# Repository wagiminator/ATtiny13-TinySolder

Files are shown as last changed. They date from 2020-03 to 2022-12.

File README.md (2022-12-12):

# TinySolder - T12 Soldering Station based on ATtiny13A
TinySolder is a simple T12 Quick Heating Soldering Station based on the ATtiny13A featuring in less than 500 bytes of code:
- Temperature measurement of the tip
- Direct control of the heater
- Temperature control via potentiometer
- Handle movement detection (by checking tilt switch)
- Time driven sleep/power off mode if iron is unused (movement detection)

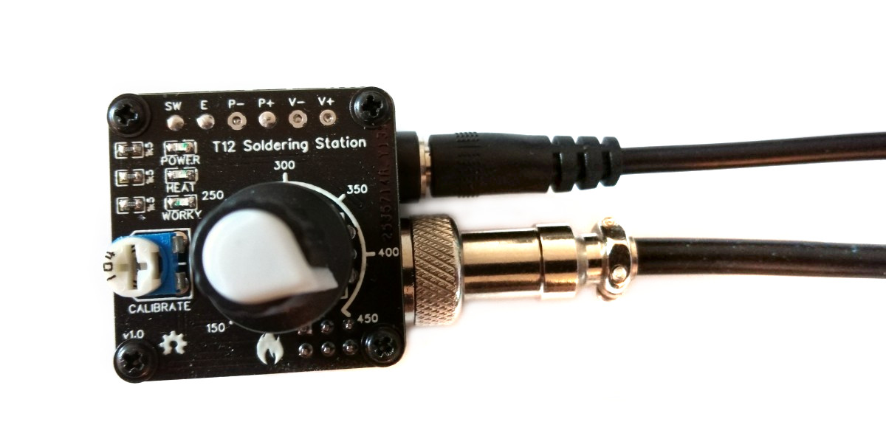
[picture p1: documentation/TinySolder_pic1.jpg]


- Project Video (YouTube): https://youtu.be/LOpmxG2Fvpo
- Design Files (EasyEDA): https://easyeda.com/wagiminator/y-attiny13-soldering-station-smd

# Hardware
## Heater Control
To switch the heater on and off, it is controlled via an [AO4435](https://datasheet.lcsc.com/szlcsc/Alpha-Omega-Semicon-AOS-AO4435_C79714.pdf) p-channel MOSFET. The MOSFET is designed for voltages up to 30V and currents up to 10A. Its resistance is relatively low at 14 milliohms, which guarantees high efficiency and low heat generation on the MOSFET itself. There are many 4435 MOSFETs available from different manufacturers with slightly different specifications. It should be ensured that a 4435 with a gate-source voltage of +/-25V is selected.

## Temperature Measurement
A thermocouple (temperature sensor) is located inside the T12 soldering tip. It creates a very small voltage depending on the temperature difference between the hot end and the cold junction. To measure this, the heater must be switched off since heater and thermocouple are connected in series. The low voltage is amplified by the OpAmp and measured by the ADC of the microcontroller. The gain factor of the OpAmp is controlled via the calibration potentiometer within fixed limits. The [LMV358](https://datasheet.lcsc.com/szlcsc/Texas-Instruments-TI-LMV358IDR_C63813.pdf) is a very cheap and versatile OpAmp, but not the ideal choice for this task because it has a fairly high input offset voltage and is quite noisy. For this kind of soldering station, however, it delivers completely sufficient values. Should a higher accuracy be required, an [OPA2330AIDR](https://datasheet.lcsc.com/szlcsc/1810181613_Texas-Instruments-OPA2330AIDR_C128746.pdf) or [OPA2333AIDR](https://datasheet.lcsc.com/szlcsc/1809200040_Texas-Instruments-OPA2333AIDR_C38732.pdf) can be used instead of the LMV358. Since these OpAmps have the same pinout, no further changes need to be made.

## Voltage Regulator
Since the ATtiny13A and the OpAmp only consume very little power, a small voltage regulator of the type [78L05](https://datasheet.lcsc.com/szlcsc/1811151533_Guangdong-Hottech-78L05_C181132.pdf) is completely sufficient for obtaining the 5V supply voltage. Because of the low current it has to deliver, it hardly heats up despite the relatively high voltage gradient.

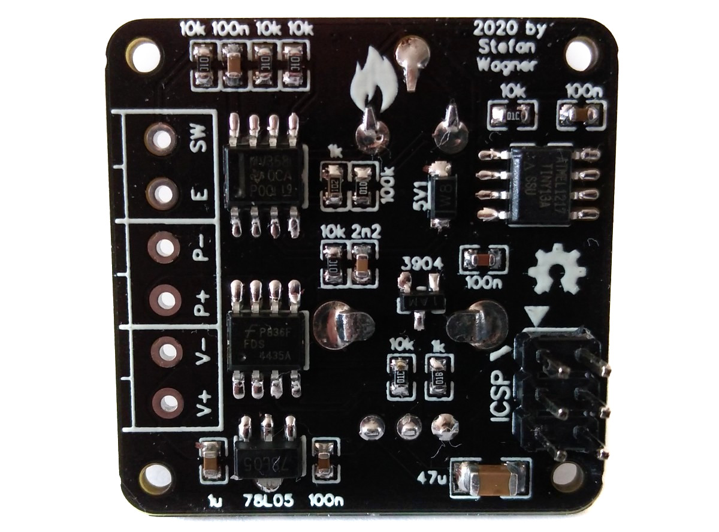
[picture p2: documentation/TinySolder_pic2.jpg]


# Software
## Implementation
In order to determine the temperature of the soldering tip, the heater must first be switched off. The output voltage of the OpAmp is then measured using the analog-to-digital converter (ADC) and the temperature is determined from this using a two-step linear approximation. The setting of the temperature selection potentiometer is also determined via the ADC. If the temperature of the soldering tip is below the selected setpoint, the heater is then switched on again via the MOSFET, otherwise it remains off for the time being.

A sleep timer runs all the time, which is reset by a pin change interrupt as soon as the tilt switch in the handle of the soldering iron changes its state. If the handle is not moved for about 5 minutes, the system switches to sleep mode, in which the temperature is reduced to about 125°C. If the handle is not moved for another 5 minutes, the heater will be switched off completely. As soon as the handle is moved, the operating mode is switched back to.

The main loop of the code is shown below:
```c
// Loop
while(1) {
  // Read potentiometer setting and calculate setpoint accordingly
  poti = ADC_read(pinADC(POTI));
  if (poti < 512) setpoint = (uint32_t)(( poti        * (TEMP300 - TEMP150))>>9) + TEMP150;
  else            setpoint = (uint32_t)(((poti - 512) * (TEMP450 - TEMP300))>>9) + TEMP300;

  // Set heater according to temperature reading and setpoint
  pinLow(HEATER);                                 // shut off heater
  _delay_us(TIME2SETTLE);                         // wait for voltages to settle
  temp = ADC_read(pinADC(TEMP));                  // read temperature
  smooth = ((smooth << 3) - smooth + temp) >> 3;  // low pass filter
  if (smooth < setpoint) pinHigh(HEATER);         // turn on heater if below setpoint

  // Set status LED according to temperature and setpoint
  pinLow(LED);
  if ((smooth + 10 > setpoint) && (setpoint + 10 > smooth)) pinHigh(LED);

  // Some timing
  if (handleTimer++ > TIME2SLEEP/CYCLETIME*1000) sleep(); // sleep mode if handle unused
  _delay_ms(CYCLETIME - 8);                               // wait for next cycle
}
```

## Compiling and Uploading
### If using the Arduino IDE
- Make sure you have installed [MicroCore](https://github.com/MCUdude/MicroCore).
- Go to **Tools -> Board -> MicroCore** and select **ATtiny13**.
- Go to **Tools** and choose the following board options:
  - **Clock:**  1.2 MHz internal osc.
  - **BOD:**    BOD 2.7V
  - **Timing:** Micros disabled
- Connect your programmer to your PC and to the ICSP header on the TinySolder board.
- Go to **Tools -> Programmer** and select your ISP programmer (e.g. [USBasp](https://aliexpress.com/wholesale?SearchText=usbasp)).
- Go to **Tools -> Burn Bootloader** to burn the fuses.
- Open TinySolder.ino and click **Upload**.

### If using the precompiled hex-file
- Make sure you have installed [avrdude](https://learn.adafruit.com/usbtinyisp/avrdude).
- Connect your programmer to your PC and to the ICSP header on the TinySolder board.
- Open a terminal.
- Navigate to the folder with the hex-file.
- Execute the following command (if necessary replace "usbasp" with the programmer you use):
  ```
  avrdude -c usbasp -p t13 -U lfuse:w:0x2a:m -U hfuse:w:0xfb:m -U flash:w:tinysolder.hex
  ```

### If using the makefile (Linux/Mac)
- Make sure you have installed [avr-gcc toolchain and avrdude](http://maxembedded.com/2015/06/setting-up-avr-gcc-toolchain-on-linux-and-mac-os-x/).
- Connect your programmer to your PC and to the ICSP header on the TinySolder board.
- Open a terminal.
- Navigate to the folder with the makefile and sketch.
- Run `PROGRMR=usbasp make install` to compile, burn the fuses and upload the firmware (change PROGRMR accordingly).

# Building Instructions
In addition to the components for the PCB you will need the following:
- 3D-printed case
- GX12 Aviator Plug (4- or 5-pin depending on your iron handle)
- DC Power Jack (5.5 * 2.1 mm)
- Rocker Switch (KCD1 15 * 10 mm)
- Some wires
- 4 Self-tapping screws (2.3 * 5 mm)

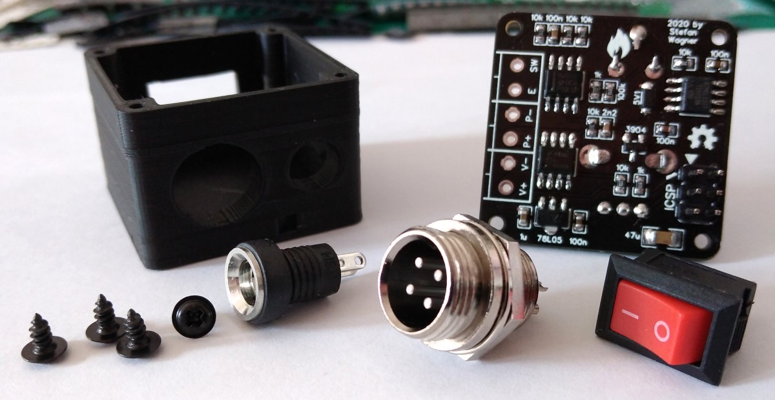
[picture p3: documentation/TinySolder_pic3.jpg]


Make sure that all parts fit nicely into the case. Solder the wires to the connectors and protect them with heat shrinks. Use thick wires (AWG18) for the power connections. Make all connections according to the schematic down below but keep in mind, that there's no standard pinout. Solder the wires directly to the corresponding pads on the pcb. To make the soldering station ESD-safe, connect the earth (E) terminal of the aviator plug to a female dupont connector and glue it into the corresponding opening on the case. Now you can connect the soldering station via a male dupont connector to an earth terminal. Upload the firmware and screw the pcb on top of the case.

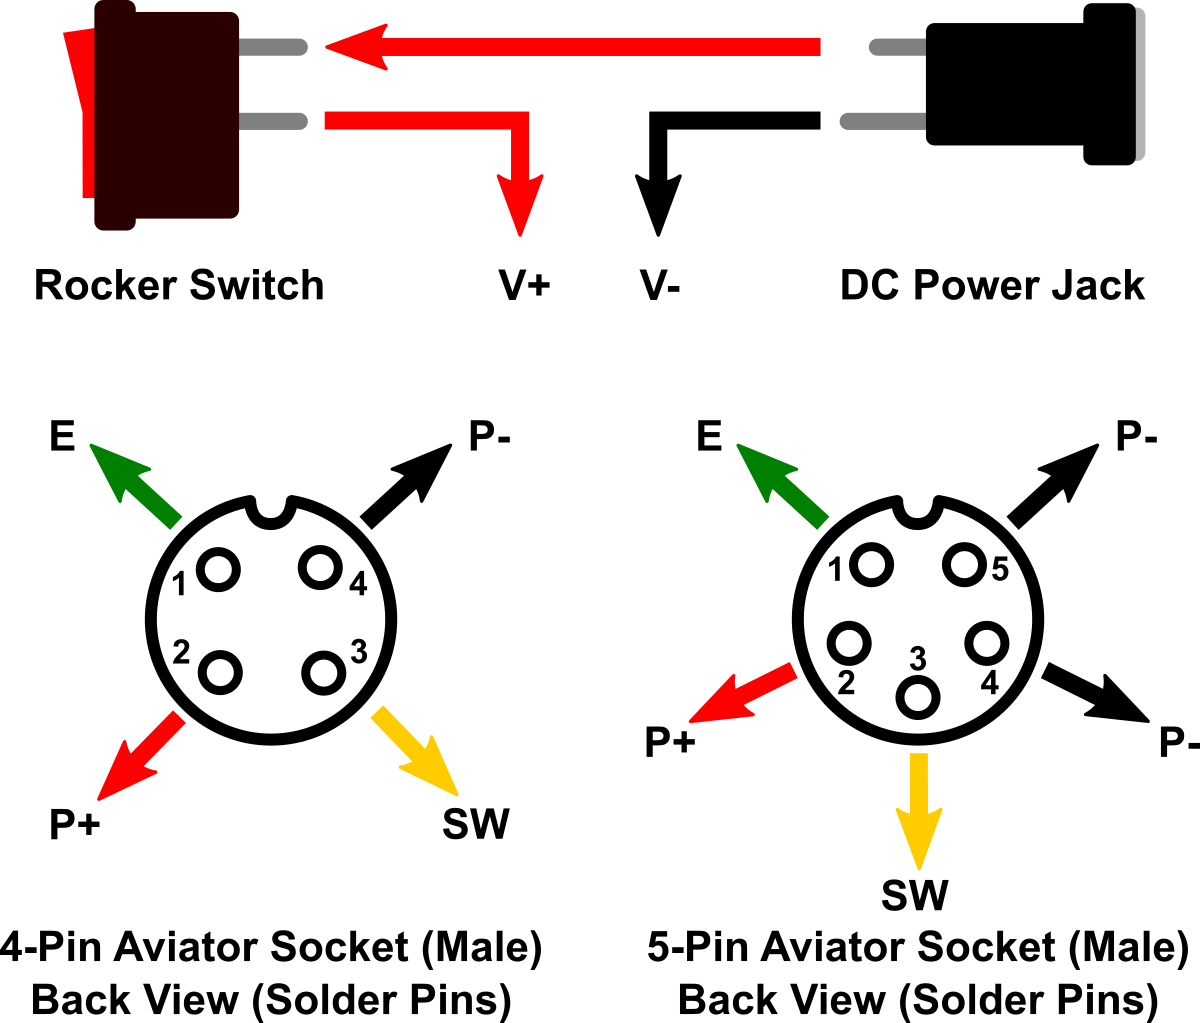
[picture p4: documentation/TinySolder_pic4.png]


The pinout shown works for the [Quecoo handles from aliexpress](https://aliexpress.com/wholesale?SearchText=quecoo+handle). Different handles may have different pinouts. If you are assembling your handle yourself, follow the scheme shown below. The video by [John Glavinos (electronics4all)](https://www.youtube.com/watch?v=DcmiFfuZw38) shows how it's done.

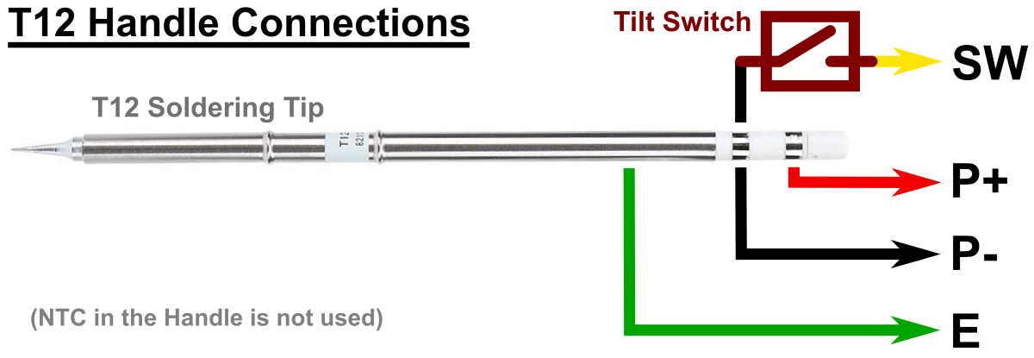
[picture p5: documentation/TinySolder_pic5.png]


# Operating Instructions
## Power Supply Specification Requirements
Choose a power supply with an output voltage between 16V and 24V which can provide an output current according to the table below. The power supply must be well stabilized. The current and power is determined by the resistance (R = 8 Ohm) of the heater.

|Voltage (U)|Current (I) = U / R|Power (P) = U² / R|
|:-|:-|:-|
|16 V|2.00 A|32 W|
|17 V|2.13 A|36 W|
|18 V|2.25 A|41 W|
|19 V|2.38 A|45 W|
|20 V|2.50 A|50 W|
|21 V|2.63 A|55 W|
|22 V|2.75 A|61 W|
|23 V|2.88 A|66 W|
|24 V|3.00 A|72 W|

## Calibrating
For calibration you need a [soldering iron tips thermometer](https://aliexpress.com/wholesale?SearchText=digital+soldering+tip+thermometer). For best results wait at least three minutes after switching on the soldering station before you start the calibration. Calibrate at your prefered temperature using the
trimpot.

## Indicator LEDs
|LED|Color|Status|
|:-|:-|:-|
|POWER|blue|lights up when the station is receiving power|
|HEAT|red|tip temperature has not reached setpoint yet|
|WORKY|green|tip temperature is at setpoint - iron is worky|
|HEAT + WORKY|red + green|blinking: iron is in sleep mode; steady: iron is in off mode; move handle to wake up|

# References, Links and Notes
1. [ATtiny13A Datasheet](http://ww1.microchip.com/downloads/en/DeviceDoc/doc8126.pdf)
2. [LMV358 Datasheet](https://datasheet.lcsc.com/szlcsc/Texas-Instruments-TI-LMV358IDR_C63813.pdf)
3. [T12 Handles on Aliexpress](https://aliexpress.com/wholesale?SearchText=T12+GX12-4pin+handle)
4. [T12 Soldering Tips on Aliexpress](https://aliexpress.com/wholesale?SearchText=T12+soldering+tips)
5. [GX12 Aviator Plugs on Aliexpress](https://aliexpress.com/wholesale?SearchText=GX12+4pin+aviator)
6. [T12 Soldering Station based on ATmega328P](https://github.com/wagiminator/ATmega-Soldering-Station)

# License


This work is licensed under Creative Commons Attribution-ShareAlike 3.0 Unported License. 
(http://creativecommons.org/licenses/by-sa/3.0/)

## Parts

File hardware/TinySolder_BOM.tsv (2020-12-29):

ID | Name | Designator | Footprint | Quantity | Manufacturer Part | Manufacturer | Supplier | Supplier Part | LCSC Assembly
1 | LMV358IDR | U3 | SOP-8_150MIL | 1 | LMV358IDR | TI | LCSC | C63813 | Yes
2 | MMBT3904 | Q2 | SOT-23_1 | 1 | 2n3904S-RTK/PS | KEC | LCSC | C18536
3 | 5V1 | D1 | ZENER-SOD-123 | 1 | BZT52C5V1 | (MDD) Jiangsu Yutai Elec | LCSC | C173407 | Yes
4 | 10k | R7,R6,R5,R1,R14,R8 | 0603 | 6 | 0603WAF1002T5E | UniOhm | LCSC | C25804
5 | 1k | R13,R11,R4,R12,R9 | 0603 | 5 | 0603WAF1001T5E | UniOhm | LCSC | C21190
6 | 100k | R3 | 0603 | 1 | 0603WAF1003T5E | UniOhm | LCSC | C25803
7 | WORKY | LED2 | LED-0603 | 1 | 19-217/GHC-YR1S2/3T | EVERLIGHT | LCSC | C72043 | Yes
8 | HEAT | LED3 | LED-0603 | 1 | KT-0603R | KENTO | LCSC | C2286 | Yes
9 | 10K | R10 | RES-TH_RK09K1130A5R | 1 | RK09K1130A5R | ALPS Electric | LCSC | C209779
10 | 78L05 | U2 | SOT-89-3_L4.5-W2.5-P1.50-LS4.2-BR | 1 | 78L05 | Guangdong Hottech | LCSC | C181132 | Yes
11 | KF350-3.5mm | P2,P1,P3 | KF350-2P | 3 | WJ2EDGVC-5.08-2P | ReliaPro | LCSC | C8445
12 | ICSP-6 | ICSP1 | ICSP-6 | 1 | ?
13 | AO4435 | Q1 | SOP-8_150MIL | 1 | AO4435 | Alpha & Omega Semicon | LCSC | C79714 | Yes
14 | POWER | LED1 | LED-0603 | 1 | 19-217/BHC-ZL1M2RY/3T | EVERLIGHT | LCSC | C72041 | Yes
15 | 100n | C5,C1,C4,C7 | 0603 | 4 | CC0603KRX7R9BB104 | YAGEO | LCSC | C14663
16 | 2n2 | C3 | 0603 | 1 | 0603B222K500NT | FH | LCSC | C1604
17 | 47u | C2 | 1206 | 1 | CL31A476MQHNNNE | SAMSUNG | LCSC | C68361
18 | 1u | C6 | 0603 | 1 | CL10A105KB8NNNC | SAMSUNG | LCSC | C15849
19 | 100k | R2 | RM065 | 1 |  |  | LCSC
20 | ATTINY13A-SSU | U1 | SOP-8_150MIL | 1 | ATTINY13A-SSU | MICROCHIP | LCSC | C14075

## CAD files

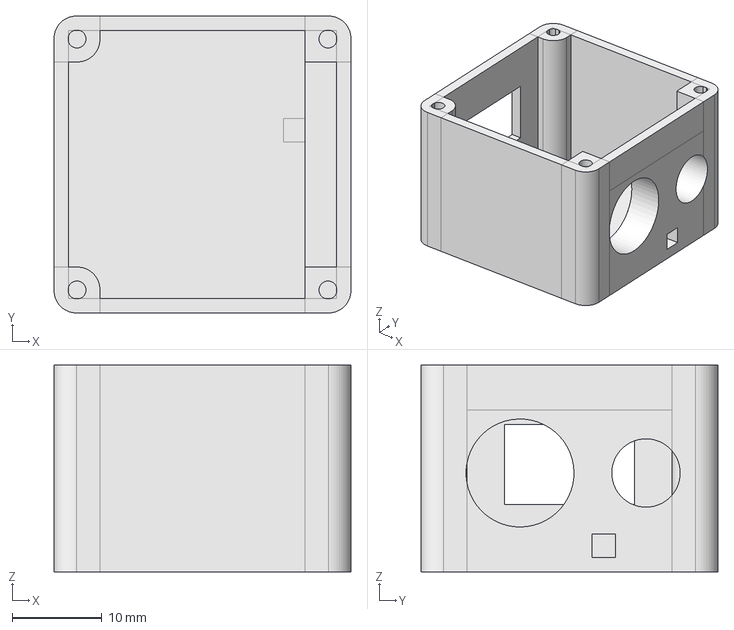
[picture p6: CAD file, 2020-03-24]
3dprint/TinySolder_case.fcstd
33.0 x 33.0 x 23.0 mm

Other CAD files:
3dprint/TinySolder_case.stl

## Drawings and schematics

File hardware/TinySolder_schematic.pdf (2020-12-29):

## Connectors

## Microcontroller

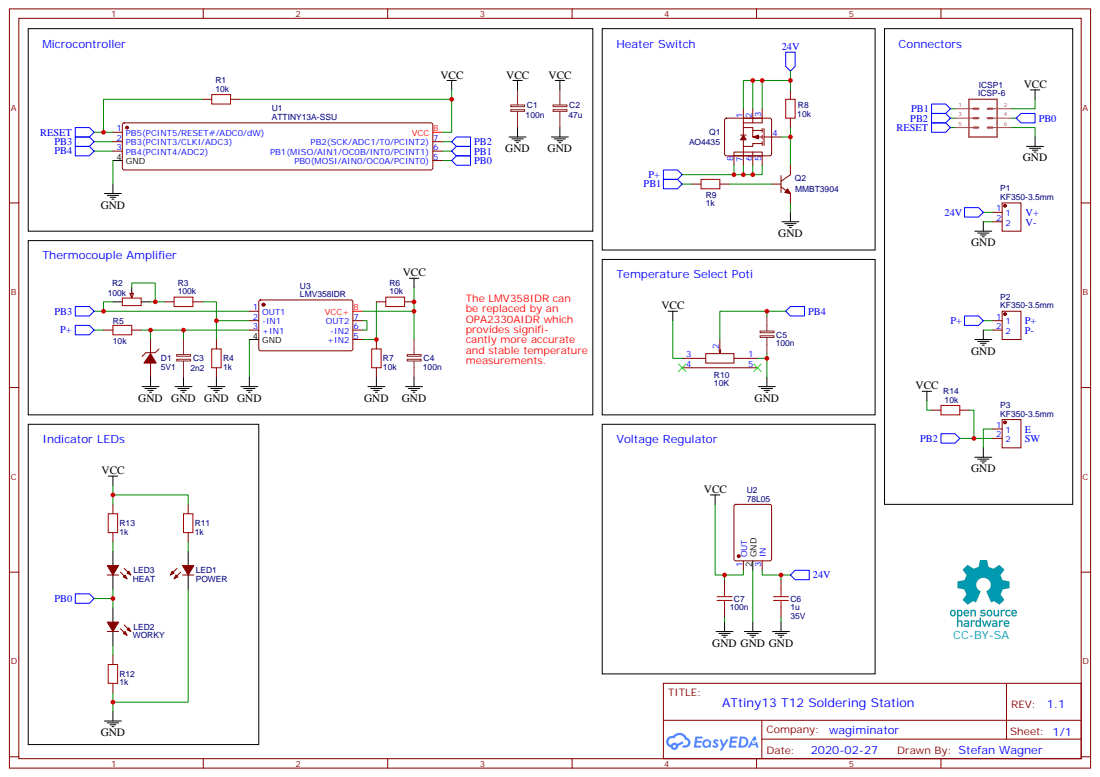
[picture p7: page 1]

The LMV358IDR can
be replaced by an
OPA2330AIDR which
provides signifi-
cantly more accurate
and stable temperature
measurements.

Drawn By: Stefan Wagner

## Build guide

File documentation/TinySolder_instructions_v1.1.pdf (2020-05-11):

## How to build the Tiny T12 SolderingStation

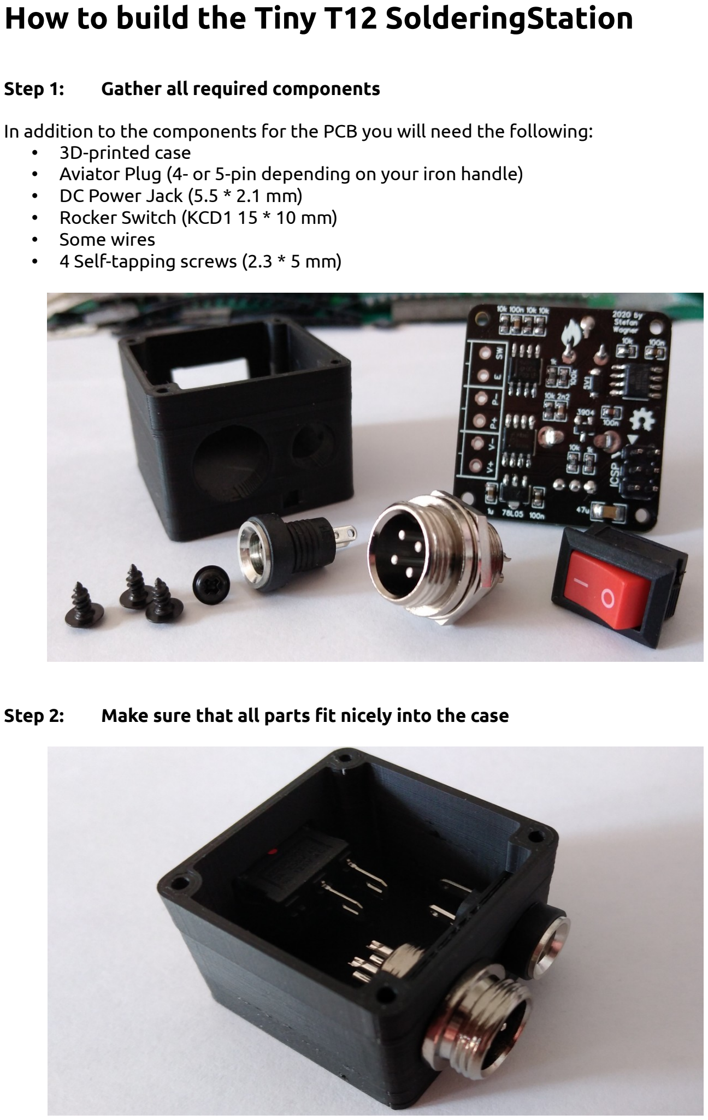
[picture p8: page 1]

Step 1: Gather all required components

In addition to the components for the PCB you will need the following:
- 3D-printed case
- Aviator Plug (4- or 5-pin depending on your iron handle)
- DC Power Jack (5.5 * 2.1 mm)
- Rocker Switch (KCD1 15 * 10 mm)
- Some wires
- 4 Self-tapping screws (2.3 * 5 mm)
Step 2: Make sure that all parts fit nicely into the case

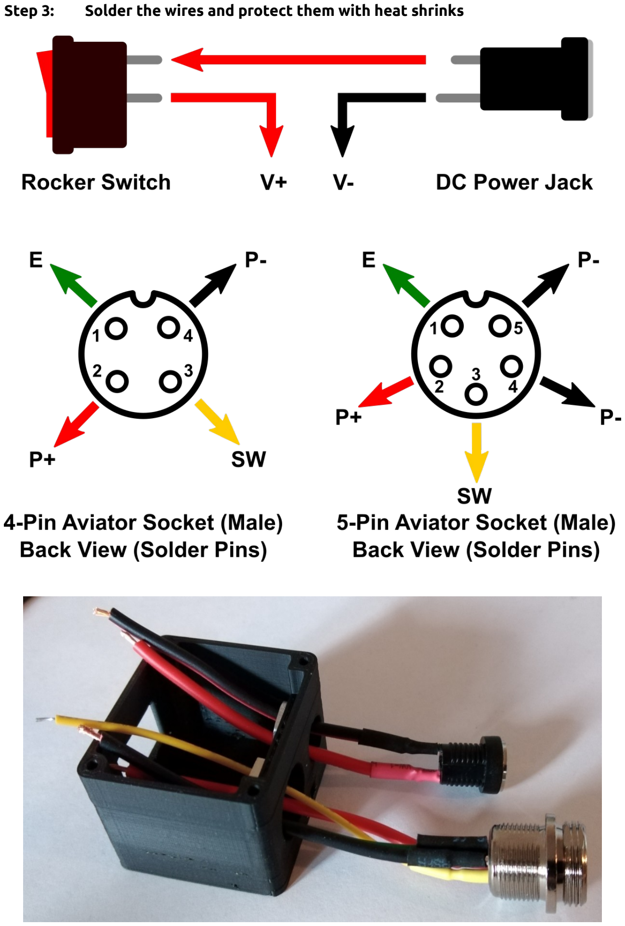
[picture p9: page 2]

Step 3: Solder the wires and protect them with heat shrinks

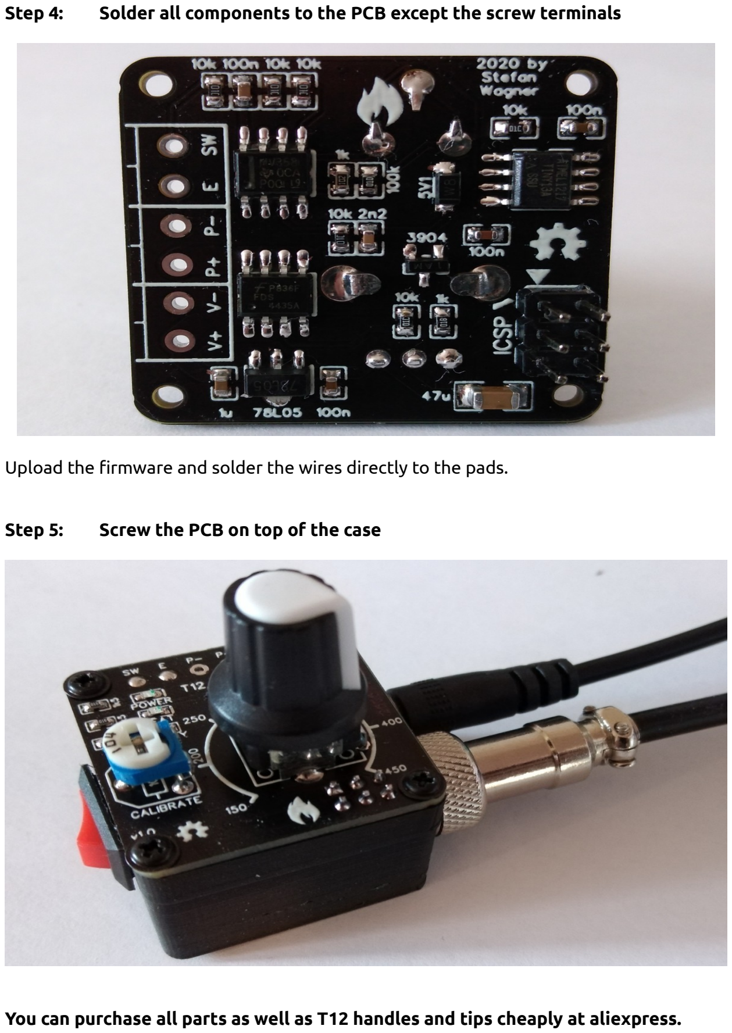
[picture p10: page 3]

Step 4: Solder all components to the PCB except the screw terminals

Upload the firmware and solder the wires directly to the pads.

Step 5: Screw the PCB on top of the case

You can purchase all parts as well as T12 handles and tips cheaply at aliexpress.

Choose a power supply with an output voltage between 16V and 24V which can provide an output current according to the table below. The power supply must be well stabilized. The current and power is determined by the resistance (R = 8 Ohm) of the heater.

Voltage (U) | Current (I) = U / R | Power (P) = U² / R
16 V | 2.00 A | 32 W
17 V | 2.13 A | 36 W
18 V | 2.25 A | 41 W
19 V | 2.38 A | 45 W
20 V | 2.50 A | 50 W
21 V | 2.63 A | 55 W
22 V | 2.75 A | 61 W
23 V | 2.88 A | 66 W
24 V | 3.00 A | 72 W

A 19V supply works best in terms of both, speed and stable temperature readings. Heat-up time to 320°C will be around 12 seconds with a 19V, 8 seconds with a 24V power supply.

TinySolder Building Instructions v1.1, 2020 by Stefan Wagner. Recent project files can be found at https://easyeda.com/wagiminator/y-attiny13-soldering-station-smd. This work is licensed under Creative Commons Attribution-ShareAlike 3.0 Unported License (http://creativecommons.org/licenses/by-sa/3.0/).

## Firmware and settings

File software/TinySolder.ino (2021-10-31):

// ===================================================================================
// Project:   TinySolder - T12 Soldering Station based on ATtiny13A
// Version:   v1.1
// Year:      2020
// Author:    Stefan Wagner
// Github:    https://github.com/wagiminator
// EasyEDA:   https://easyeda.com/wagiminator
// License:   http://creativecommons.org/licenses/by-sa/3.0/
// ===================================================================================
//
// Description:
// ------------
// Simple T12 Quick Heating Soldering Station featuring:
// - Temperature measurement of the tip
// - Direct control of the heater
// - Temperature control via potentiometer
// - Handle movement detection (by checking tilt switch)
// - Time driven sleep/power off mode if iron is unused (movement detection)
//
// Indicator LEDs:
// - steady blue          - station is powered
// - steady red           - tip temperature has not reached setpoint yet
// - steady green         - tip temperature is at setpoint - iron is worky
// - blinking red/green   - iron is in sleep mode - move handle to wake up
// - steady red and green - iron is in off mode - move handle to start again
//
// Power supply should be in the range of 16V/2A to 24V/3A and well
// stabilized.
//
// For calibration you need a soldering iron tips thermometer. For best results
// wait at least three minutes after switching on the soldering station before 
// you start the calibration. Calibrate at your prefered temperature.
//
// Wiring:
// -------
//                         +-\/-+
//      --- RST ADC0 PB5  1|°   |8  Vcc
// Temp ------- ADC3 PB3  2|    |7  PB2 ADC1 -------- Tilt Switch
// Poti ------- ADC2 PB4  3|    |6  PB1 AIN1 OC0B --- Heater
//                   GND  4|    |5  PB0 AIN0 OC0A --- LED
//                         +----+
//
// Compilation Settings:
// ---------------------
// Controller:  ATtiny13A
// Core:        MicroCore (https://github.com/MCUdude/MicroCore)
// Clockspeed:  1.2 MHz internal
// BOD:         BOD 2.7V
// Timing:      Micros disabled
//
// Leave the rest on default settings. Don't forget to "Burn bootloader"!
// No Arduino core functions or libraries are used. Use the makefile if 
// you want to compile without Arduino IDE.
//
// Fuse settings: -U lfuse:w:0x2a:m -U hfuse:w:0xfb:m


// ===================================================================================
// Libraries and Definitions
// ===================================================================================

// Libraries
#include <avr/io.h>             // for gpio
#include <avr/sleep.h>          // for the sleep modes
#include <avr/interrupt.h>      // for the interrupts
#include <util/delay.h>         // for delays

// Pin definitions
#define LED           PB0       // connected to indicator LEDs
#define HEATER        PB1       // connected to gate of heater control MOSFET
#define SWITCH        PB2       // connected to tilt switch of handle
#define TEMP          PB3       // connected to P+ of tip (temp measurement)
#define POTI          PB4       // connected to temp selection pot

// ADC temperature calibration values
#define TEMPSLEEP     100       // ADC3 in sleep mode
#define TEMP150       118       // ADC3 at 150°C
#define TEMP300       221       // ADC3 at 300°C
#define TEMP450       324       // ADC3 at 450°C

// Timer definitions
#define CYCLETIME      50       // cycle delay time in milliseconds
#define TIME2SETTLE   900       // voltage settle time in microseconds
#define TIME2SLEEP    300       // time to enter sleep mode in seconds
#define TIME2OFF      600       // time to shut off heater in seconds

// Pin manipulation macros
#define pinInput(x)   DDRB  &= ~(1<<(x))  // set pin to INPUT
#define pinOutput(x)  DDRB  |=  (1<<(x))  // set pin to OUTPUT
#define pinLow(x)     PORTB &= ~(1<<(x))  // set pin to LOW
#define pinHigh(x)    PORTB |=  (1<<(x))  // set pin to HIGH
#define pinToggle(x)  PINB  |=  (1<<(x))  // TOGGLE pin
#define pinDisable(x) DIDR0 |=  (1<<(x))  // disable digital input buffer
#define pinIntEn(x)   PCMSK |=  (1<<(x))  // enable pin change interrupt
#define pinRead(x)    (PINB &   (1<<(x))) // READ pin
#define pinADC(x)     ((x)==2?1:((x)==3?3:((x)==4?2:0))) // convert pin to ADC port

// Global variables
volatile uint16_t handleTimer;  // time since the handle was last moved

// ===================================================================================
// ADC Implementation
// ===================================================================================

// Init ADC
void ADC_init(void) {
  ADCSRA = (1<<ADEN)                  // enable ADC
         | (1<<ADPS1) | (1<<ADPS0)    // set ADC clock prescaler to 8
         | (1<<ADIE);                 // ADC interrupts enable
}

// Average several ADC readings in sleep mode to denoise
uint16_t ADC_read(uint8_t port) {
  uint16_t result = 0;
  ADCSRA |= (1<<ADIF);                // turn off any pending interrupt
  ADMUX = port;                       // set port and reference to AVcc   
  set_sleep_mode (SLEEP_MODE_ADC);    // sleep during sample for noise reduction
  for (uint8_t i=16; i; i--) {        // get 16 readings
    sleep_mode();                     // go to sleep while taking ADC sample
    while (ADCSRA & (1<<ADSC));       // make sure sampling is completed
    result += ADC;                    // add them up
  }
  return (result >> 4);               // divide by 16 and return value
}

// ADC interrupt service routine
EMPTY_INTERRUPT(ADC_vect);            // nothing to be done here

// ===================================================================================
// Sleep Mode Implementation
// ===================================================================================

// Set sleep mode for iron
void sleep(void) {
  while(handleTimer) {                            // repeat until handle was moved
    pinLow(HEATER);                               // shut off heater
    if(handleTimer < TIME2OFF/CYCLETIME*1000) {   // if not in off mode
      handleTimer++;                              // increase timer
      _delay_us(TIME2SETTLE);                     // wait for voltages to settle
      uint16_t temp = ADC_read(pinADC(TEMP));     // read temperature
      if(temp < TEMPSLEEP) pinHigh(HEATER);       // turn on heater if below sleep temp
      pinToggle(LED);                             // toggle LED
    } else {                                      // if in off mode
      pinInput(LED);                              // turn red and green LED on
    }
    _delay_ms(CYCLETIME - 8);                     // wait for next cycle
  }
  pinOutput(LED);                                 // set LED pin as output again
}

// Pin change interrupt service routine (when handle was moved)
ISR(PCINT0_vect){
  handleTimer = 0;                                // reset handle timer
}

// ===================================================================================
// Main Function
// ===================================================================================

int main(void) {
  // Local variables
  uint16_t poti, temp, smooth, setpoint;

  // Setup pins
  pinOutput(LED);                       // LED pin as output
  pinOutput(HEATER);                    // heater control pin as output
  pinHigh(SWITCH);                      // pull-up for switch
  pinDisable(TEMP);                     // disable digital input buffer
  pinDisable(POTI);                     // disable digital input buffer

  // Setup pin change interrupt
  GIMSK = (1<<PCIE);                    // pin change interrupts enable
  pinIntEn(SWITCH);                     // turn on interrupt on switch pin
  sei();                                // enable global interrupts

  // Setup ADC and read temperature as start value for smoothing
  ADC_init();
  smooth = ADC_read(pinADC(TEMP));

  // Loop
  while(1) {
    // Read potentiometer setting and calculate setpoint accordingly
    poti = ADC_read(pinADC(POTI));
    if(poti < 512) setpoint = (uint32_t)(( poti        * (TEMP300 - TEMP150))>>9) + TEMP150;
    else           setpoint = (uint32_t)(((poti - 512) * (TEMP450 - TEMP300))>>9) + TEMP300;

    // Set heater according to temperature reading and setpoint
    pinLow(HEATER);                                 // shut off heater
    _delay_us(TIME2SETTLE);                         // wait for voltages to settle
    temp = ADC_read(pinADC(TEMP));                  // read temperature
    smooth = ((smooth << 3) - smooth + temp) >> 3;  // low pass filter
    if(smooth < setpoint) pinHigh(HEATER);          // turn on heater if below setpoint

    // Set status LED according to temperature and setpoint
    pinLow(LED);
    if((smooth + 10 > setpoint) && (setpoint + 10 > smooth)) pinHigh(LED);

    // Some timing
    if(handleTimer++ > TIME2SLEEP/CYCLETIME*1000) sleep();  // sleep mode if handle unused
    _delay_ms(CYCLETIME - 8);                               // wait for next cycle
  }
}

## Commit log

2020-11-13 Update files
    [TinySolder_case.fcstd, TinySolder_case.stl]
2021-10-31 Editorial changes
    [TinySolder_BOM.tsv, TinySolder_BOM_v1.0.tsv]
